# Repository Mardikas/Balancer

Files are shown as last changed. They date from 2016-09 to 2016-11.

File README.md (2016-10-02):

# Balancer
A (semi)self-driving (fully)self-balancing robot

Different PIDs:

	40;140;20 <--super stiff, but fails with strong tilts (overcompensates);
	40,90,80 <-- also quite stiff, does not overcompensate;

ToDo:

	*Try this PID library https://github.com/br3ttb/Arduino-PID-Library/blob/master/README.txt
	*Enable zeroing function for setpoint finding, so that when the machine stops for long enough, it will not start drifting in the other direction.
	*figure out a way (electronical preffered, mechanically different connections otherwise) to connect UNO and motor driver as a shield while still being able to use pin 2)
	EDIT: found a neat mechanical and aesthetical way to choose which pins to use
	*Gyro calibration offsets (MPU6050): acelX acelY acelZ giroX giroY giroZ -88	-290	2279	-599	39	15
	*Print out a good prototype chassis
	*Add encoder pin layout to PIN LAYOUT
	*Done:
		*Write a motor library (since default library doesn't work) //have implemented motor functions, but not in a separate library
		*Write simple code that keeps the robot upright //done more or less, perhaps needs even more fine tuning
		*Write simple code that enables for the robot to drive forward/backward, turn right and left //done, works semi-ok
		*Write a code for controlling the robot via bluetooth with Android //DONE!
	*Write a code for using encoders to keep speed/balance better; make balancing and driving code more ergonomical&better
	*Write code for mapping and then reproducing path
	*Write code for autonomous drive on a table withouth falling off nor bumping into obstacles
	*Write code for line following
	
	*Put a glass of water on robot and drive so

Done for now! Next step?

PIN LAYOUT:
	
	Gyro uses:
	
		*3.3V
		*GND
		*A4 (I2c) SDA
		*A5 (I2c) SCL
	
	Bluetooth uses:
	
		*3.3V
		*GND
		*D0(RX)
		*D1(TX)
	
	Motor shield uses:
	
		*D2 - Motor 1 direction input A
		*D4 - Motor 1 direction input B
		*D6 - Motor 1 enable input/fault output
		*D7 - Motor 2 direction input A
		*D8 - Motor 2 direction input B
		*D9 - Motor 1 speed input
		*D10 - Motor 2 speed input
		*D12 - Motor 2 enable input/fault output
		*A0 - Motor 1 current sense output - NOT USED
		*A1 Motor 2 current sense output - NOT USED
		*MUST share a common ground with Arduino
	
	Encoders use:
	
		*TBA!

Sources:
	High frequency PWM:
		http://forum.arduino.cc/index.php/topic,117425.0.html

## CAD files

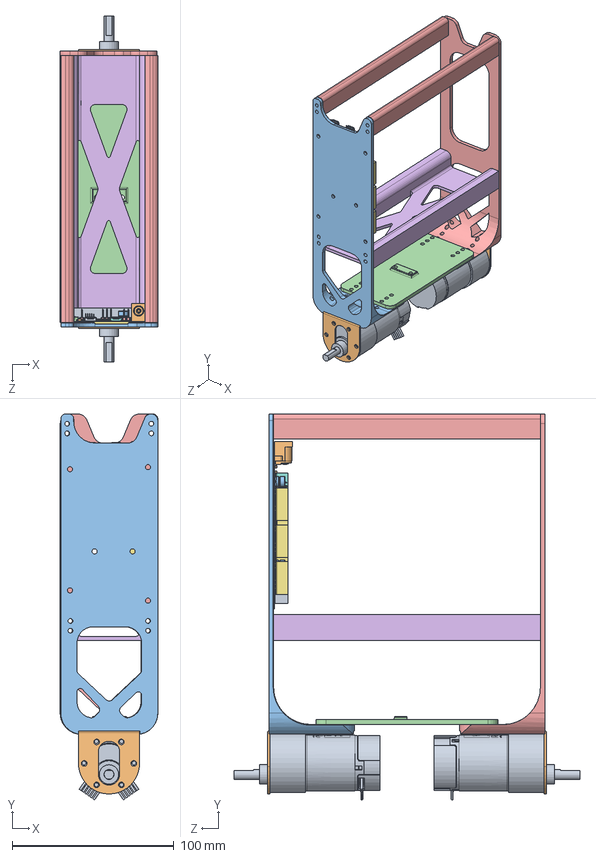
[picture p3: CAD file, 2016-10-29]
drawings/v2/Robot_assembly.SLDASM
60.4 x 238.7 x 213.7 mm
37d-gearmotor-19-30-encoder x 2
Pololu Stamped Aluminum L-Bracket Pair for 37D mm Metal Gearmotors x 2
Arduino_due_mount_wall
Horizontal_mount_battery_mount
Motor_controller_mount_wall_
horizontal_struct
PCB - Arduino
MicroUSB B - Hirose - ZX62D-B-5P8
MicroUSB AB - Hirose - ZX62D-AB-5P8
Power Jack - Kycon - KLDHCX-0202-A
LED - Kingbright - KPT-3216EC x 4
Microchip - Atmel - SAM3X8EAU
Berg Header - 2.54 x 2 x 8
Berg Header - 1.27 x 10
Berg Header Receptacle 2.54 x 8 - FCI - 66951-008LF x 5
Berg Header Receptacle 2.54 x 10 - FCI - 66951-010LF
Berg Header Receptacle 2.54 x 36 - FCI - 66953-018LF
Capacitor x 9
Capacitor - Nichicon - UUR1C101MCL1GS x 2
Switch - ESwitch - TLE3303
horizontal_struct_upper x 2

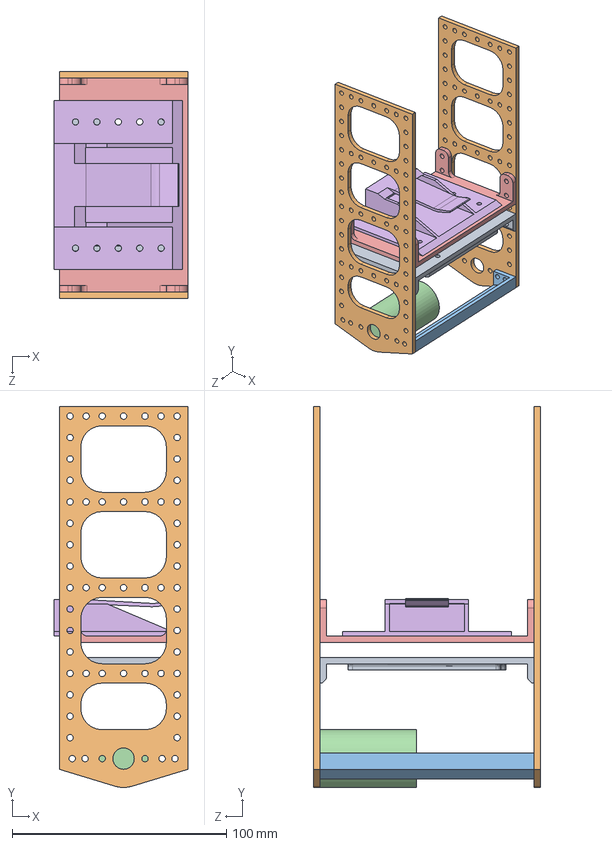
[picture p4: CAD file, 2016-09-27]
drawings/Solidworks/Assembly.SLDASM
62.5 x 178.0 x 106.0 mm
Arduino_mount_reviewed
vertical_panel x 2
struct_lower
motor
battery_mount_mount
battery_mount

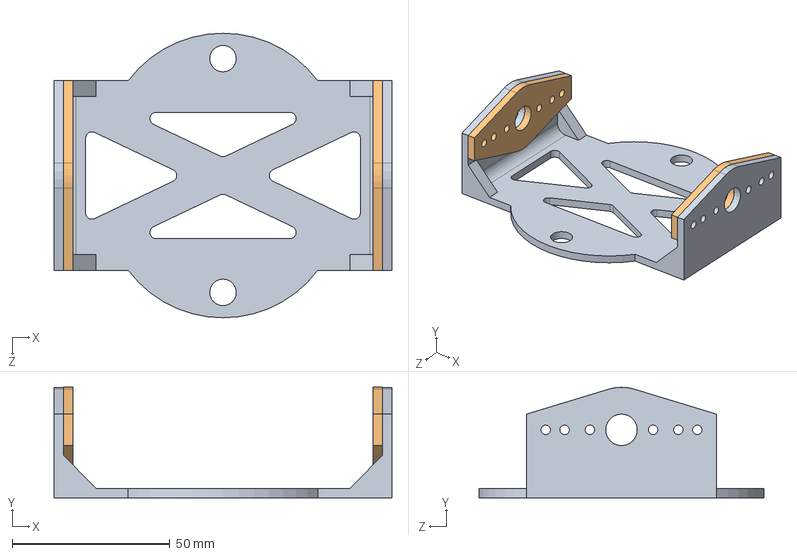
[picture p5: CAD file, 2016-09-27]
drawings/Solidworks/Assem1.SLDASM
107.0 x 35.0 x 90.1 mm
motor_floor
motor_mount x 2

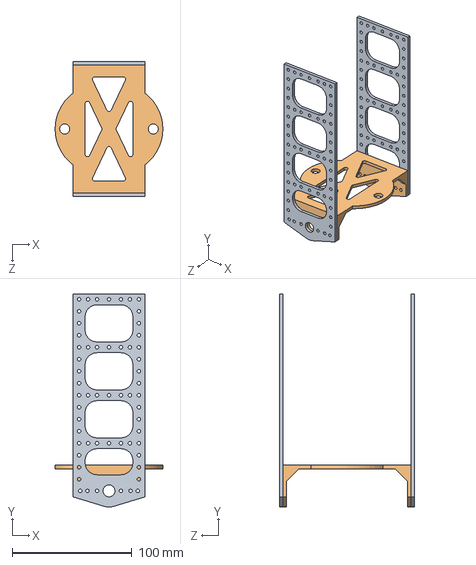
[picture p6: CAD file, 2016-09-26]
drawings/Solidworks/Robot_assembly.SLDASM
90.1 x 177.9 x 113.0 mm
vertical_panel x 2
motor_floor

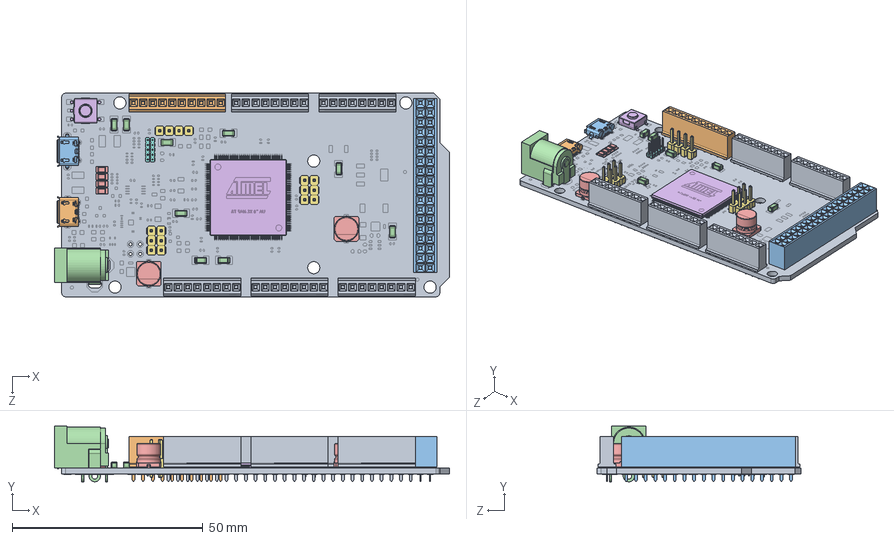
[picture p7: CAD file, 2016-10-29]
drawings/v2/Arduino Due/ARDUINO DUE.SLDASM
103.5 x 14.6 x 53.3 mm
PCB - Arduino
MicroUSB B - Hirose - ZX62D-B-5P8
MicroUSB AB - Hirose - ZX62D-AB-5P8
Power Jack - Kycon - KLDHCX-0202-A
LED - Kingbright - KPT-3216EC x 4
Microchip - Atmel - SAM3X8EAU
Berg Header - 2.54 x 2 x 8
Berg Header - 1.27 x 10
Berg Header Receptacle 2.54 x 8 - FCI - 66951-008LF x 5
Berg Header Receptacle 2.54 x 10 - FCI - 66951-010LF
Berg Header Receptacle 2.54 x 36 - FCI - 66953-018LF
Capacitor x 9
Capacitor - Nichicon - UUR1C101MCL1GS x 2
Switch - ESwitch - TLE3303

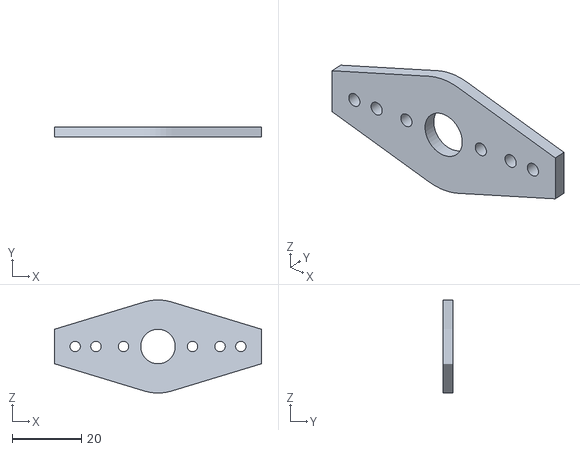
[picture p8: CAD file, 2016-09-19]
drawings/Printer/motor_mount.STL
60.0 x 3.00 x 27.0

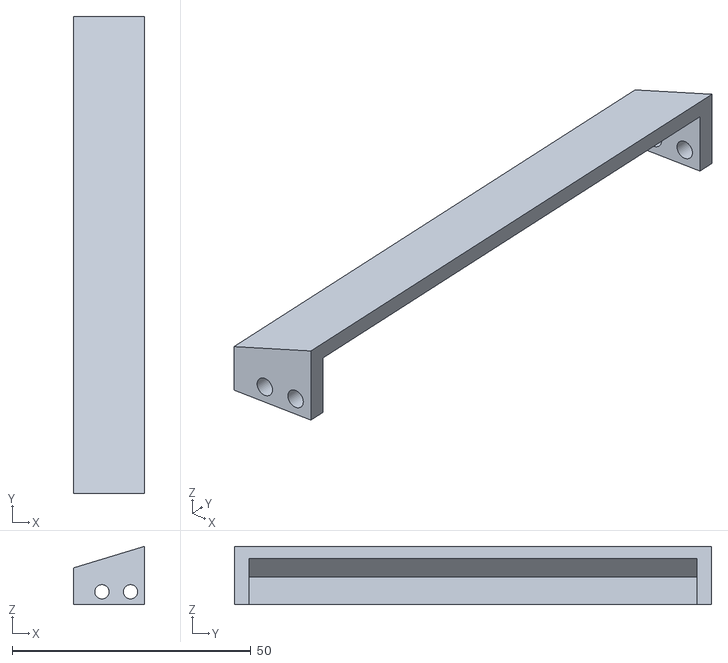
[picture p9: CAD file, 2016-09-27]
drawings/Printer/New_patch/struct_lower.STL
15.0 x 100.0 x 12.3

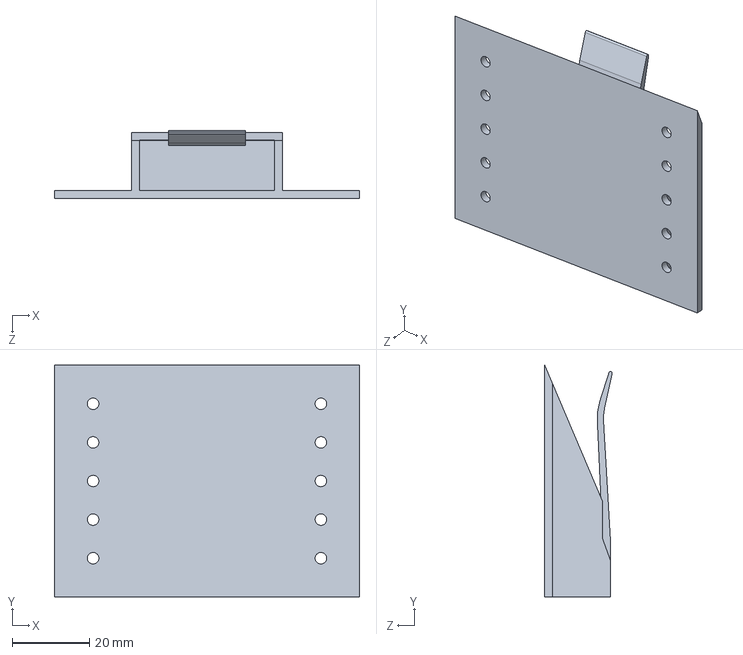
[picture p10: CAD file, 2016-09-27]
drawings/Solidworks/battery_mount.SLDPRT
79.0 x 60.0 x 17.5 mm

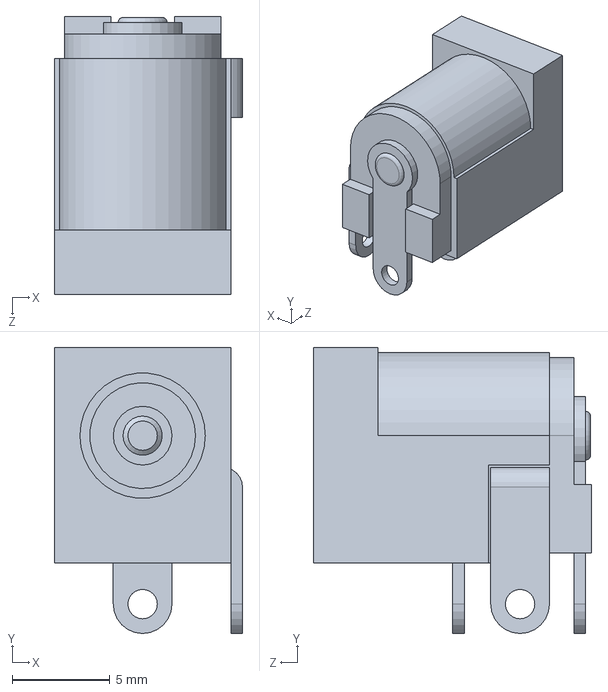
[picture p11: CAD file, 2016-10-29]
drawings/v2/Arduino Due/Power Jack - Kycon - KLDHCX-0202-A.SLDPRT
9.60 x 14.6 x 14.2 mm

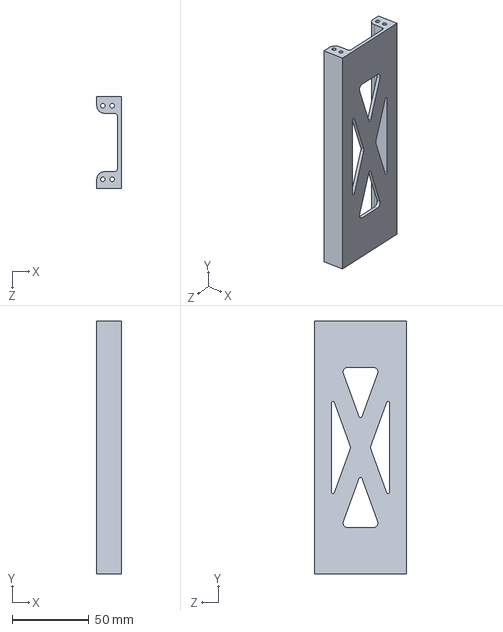
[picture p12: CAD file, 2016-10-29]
drawings/v2/horizontal_struct.SLDPRT
16.0 x 165.0 x 60.0 mm

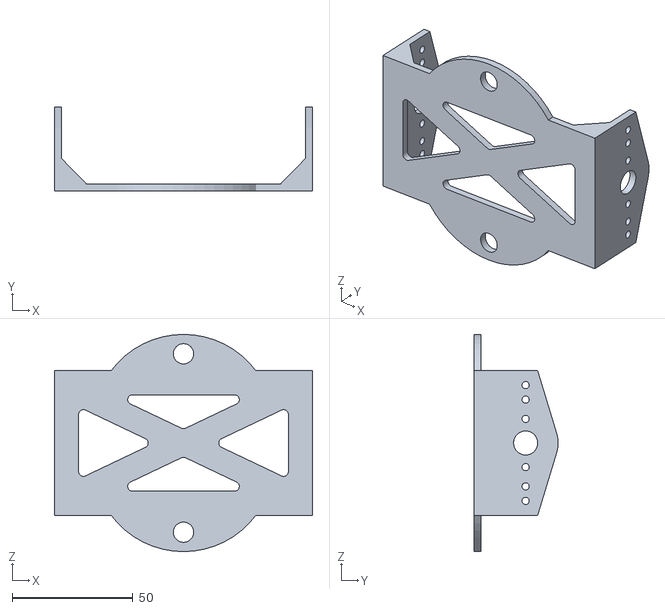
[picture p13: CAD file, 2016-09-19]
drawings/Printer/motor_floor.STL
107.0 x 35.0 x 90.1

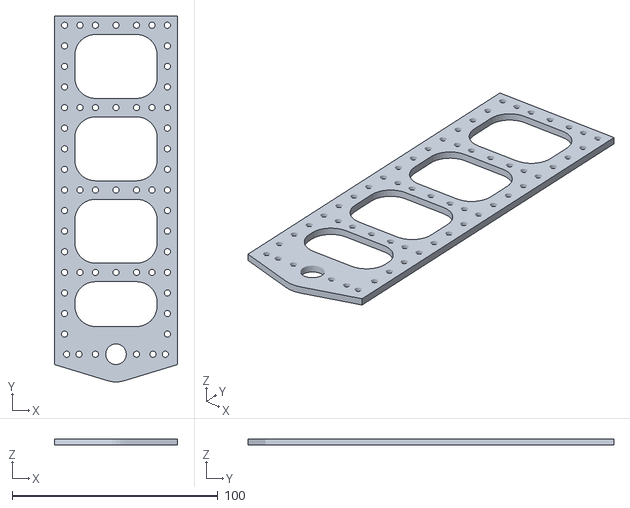
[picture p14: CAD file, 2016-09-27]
drawings/Printer/New_patch/vertical_panel.STL
60.0 x 178.0 x 3.00

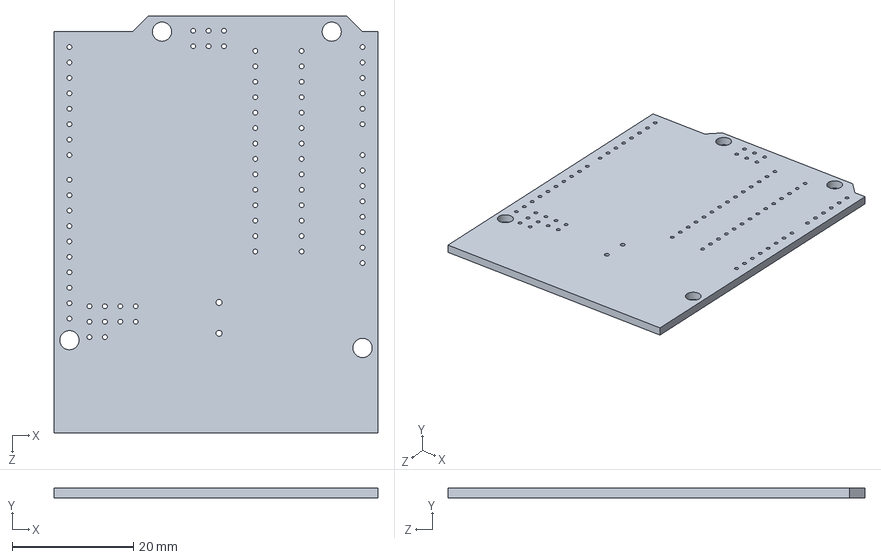
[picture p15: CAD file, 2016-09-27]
drawings/Solidworks/unoboard_blue.SLDPRT
53.3 x 1.65 x 68.6 mm

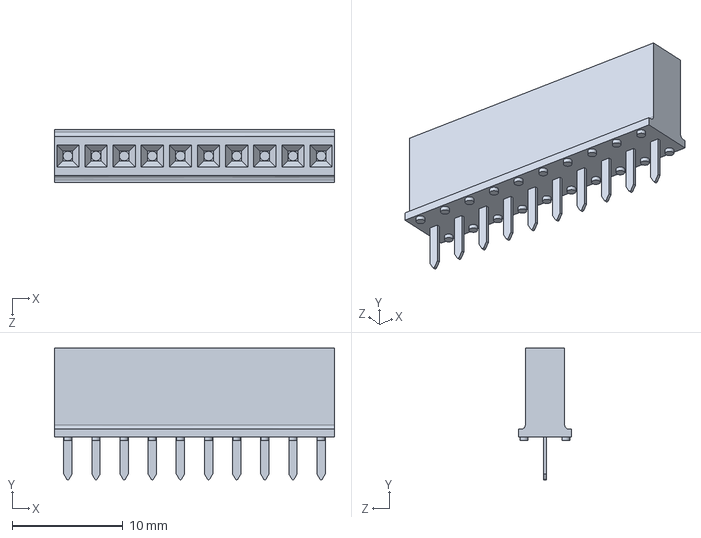
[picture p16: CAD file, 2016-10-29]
drawings/v2/Arduino Due/Berg Header Receptacle 2.54 x 10 - FCI - 66951-010LF.SLDPRT
25.3 x 11.9 x 4.78 mm

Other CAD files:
drawings/Printer/Arduino_MPU6050_Mount.STL
drawings/Printer/New_patch/battery_mount_mount.STL
drawings/Solidworks/Arduino_mount_reviewed.SLDPRT
drawings/v2/Arduino Due/Switch - ESwitch - TLE3303.SLDPRT
drawings/Printer/Motor_controller_mount.STL
drawings/Printer/New_patch/Arduino_mount_reviewed.STL
drawings/Printer/New_patch/battery_mount.STL
drawings/Solidworks/Arduino_MPU6050_Mount.SLDPRT
drawings/Solidworks/MPU6050_base.SLDPRT
drawings/Solidworks/Motor_controller_mount.SLDPRT
drawings/Solidworks/battery_mount_mount.SLDPRT
drawings/Solidworks/motor.SLDPRT
drawings/Solidworks/motor_floor.SLDPRT
drawings/Solidworks/motor_floor_rod_stabilizer.SLDPRT
drawings/Solidworks/motor_mount.SLDPRT
drawings/Solidworks/struct_lower.SLDPRT
drawings/Solidworks/vertical_panel.SLDPRT
drawings/v2/37d-gearmotor-19-30-encoder.SLDPRT
drawings/v2/37d-gearmotor-19-30-encoder.step
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

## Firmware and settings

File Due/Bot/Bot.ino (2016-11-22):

#include <PWM.h>
#include "DualVNH5019MotorShield.h"
DualVNH5019MotorShield md;
// EVERYTHING GYRO RELATED
#include "I2Cdev.h"
#include "MPU6050_6Axis_MotionApps20.h"
#if I2CDEV_IMPLEMENTATION == I2CDEV_ARDUINO_WIRE
  #include "Wire.h"
#endif

MPU6050 mpu;

#define INTERRUPT_PIN 24  // use pin 2 on Arduino Uno & most boards
bool dmpReady = false;  // set true if DMP init was successful
uint8_t mpuIntStatus;   // holds actual interrupt status byte from MPU
uint8_t devStatus;      // return status after each device operation (0 = success, !0 = error)
uint16_t packetSize;    // expected DMP packet size (default is 42 bytes)
uint16_t fifoCount;     // count of all bytes currently in FIFO
uint8_t fifoBuffer[64]; // FIFO storage buffer

Quaternion q;           // [w, x, y, z]         quaternion container
VectorInt16 aa;         // [x, y, z]            accel sensor measurements
VectorInt16 aaReal;     // [x, y, z]            gravity-free accel sensor measurements
VectorInt16 aaWorld;    // [x, y, z]            world-frame accel sensor measurements
VectorFloat gravity;    // [x, y, z]            gravity vector
float euler[3];         // [psi, theta, phi]    Euler angle container
float ypr[3];           // [yaw, pitch, roll]   yaw/pitch/roll container and gravity vector

volatile bool mpuInterrupt = false;     // indicates whether MPU interrupt pin has gone high
void dmpDataReady() {
    mpuInterrupt = true;
}

void gyro_init();
// END OF EVERYTHING GYRO RELATED

//////////////AVG ERROR CALCULATION STUFF////////////
#include "RunningAverage.h"
RunningAverage avg_error_array(200);
void calc_avg_error();
int avg_error;
/////////////////////////////////////////////////////
void calc_balance_PID();
void calc_setpoint_PID();
void receive_data();
void stopIfFault();
void receive_data();

char safety=0;

//Balancing PID related values
int error, P, D, last_P;
long I = 0;
int speed=0;
int I_gain_num = 3;
int I_gain_den = 1000;
int D_gain_num = 20;
int D_gain_den = 100;
int P_gain_num = 70;//numenator
int P_gain_den = 100;//denominator
int max_i = 200;
int target_speed=0;

//
//setpoint PID related values
int stp_error=0;
int last_stp_error=0;
long int stp_I=0;
int stp_P=0;
int stp_D=0;
int stp_P_gain=500;
int stp_I_gain=6600;
int stp_D_gain=150;

char buff[4];
float offset;
int turn;
int dir;
int turn_amount;
int direction_amount;
int remap_counter=0;
int remap_normalise_counter=0;
int remap_limit=10;
int setpoint_offset=0;
int motor_left=0;
int motor_right=0;

/////////////BEGINNING OF MOTOR STUFF/////////////
#include <Encoder.h>

Encoder motor_left_pos(38, 39);
Encoder motor_right_pos(40, 41);

int calc_motor_left_PWM();
int calc_motor_right_PWM();

int check_motor_safety();
//LEFT MOTOR STUFF
long motor_left_last_pos  = 0;
long motor_left_current_pos=0;
int motor_left_PWM=0;
int motor_left_current_speed=0;
int motor_left_target_speed=10;

int motor_left_speed_error=0;
int motor_left_P=0;
long motor_left_I=0;
int motor_left_D=0;
int motor_left_last_speed_error=0;

int motor_left_P_gain=10;
int motor_left_I_gain=1;
int motor_left_D_gain=10;

//RIGHT MOTOR STUFF
long motor_right_last_pos=0;
long motor_right_current_pos=0;
int motor_right_PWM=0;
int motor_right_current_speed=0;
int motor_right_target_speed=10;

int motor_right_speed_error=0;
int motor_right_P=0;
long motor_right_I=0;
int motor_right_D=0;
int motor_right_last_speed_error=0;

int motor_right_P_gain=10;
int motor_right_I_gain=1;
int motor_right_D_gain=10;

/////////////////END OF MOTOR STUFF//////////////

void printData();

// ================================================================
// ===                      INITIAL SETUP                       ===
// ================================================================

void setup() {
  
  gyro_init();
  md.init();
  
  P=I=D=error=last_P=0;
  dir=0;
  turn=0;
  turn_amount=100;
  direction_amount=5;
  target_speed=0;

  Serial1.begin(9600);
}



// ================================================================
// ===                    MAIN PROGRAM LOOP                     ===
// ================================================================

void loop() {
    receive_data();
    // if programming failed, don't try to do anything
    if (!dmpReady) return;

    // wait for MPU interrupt or extra packet(s) available
    while (!mpuInterrupt && fifoCount < packetSize) {
        // other program behavior stuff here
        // .
        // .
        // .
        // if you are really paranoid you can frequently test in between other
        // stuff to see if mpuInterrupt is true, and if so, "break;" from the
        // while() loop to immediately process the MPU data
        // .
        // .
        // .
        while((millis()%5)!=0);
       

        check_safety();
        if(safety!=0){
          md.setSpeeds(0,0);
        }
        //If robot is lying down, stop the motors

        //if it's not horisontal: DRIVE and BALANCE! :)
        else{
          calc_avg_error();
          calc_setpoint_PID();
          calc_balance_PID();
          //md.setSpeeds(motor_left_target_speed+turn+target_PWM, motor_right_target_speed-turn+target_PWM);
          md.setSpeeds(motor_left_PWM, motor_right_PWM);
        }
        printData();
    }

    // reset interrupt flag and get INT_STATUS byte
    mpuInterrupt = false;
    mpuIntStatus = mpu.getIntStatus();

    // get current FIFO count
    fifoCount = mpu.getFIFOCount();

    // check for overflow (this should never happen unless our code is too inefficient)
    if ((mpuIntStatus & 0x10) || fifoCount == 1024) {
        // reset so we can continue cleanly
        mpu.resetFIFO();
        Serial.println(F("FIFO overflow!"));

    // otherwise, check for DMP data ready interrupt (this should happen frequently)
    } else if (mpuIntStatus & 0x02) {
        // wait for correct available data length, should be a VERY short wait
        while (fifoCount < packetSize) fifoCount = mpu.getFIFOCount();

        // read a packet from FIFO
        mpu.getFIFOBytes(fifoBuffer, packetSize);
        
        // track FIFO count here in case there is > 1 packet available
        // (this lets us immediately read more without waiting for an interrupt)
        fifoCount -= packetSize;
            // display Euler angles in degrees
            mpu.dmpGetQuaternion(&q, fifoBuffer);
            mpu.dmpGetGravity(&gravity, &q);
            mpu.dmpGetYawPitchRoll(ypr, &q, &gravity);
        // blink LED to indicate activity
    }
}

void gyro_init(){
      // join I2C bus (I2Cdev library doesn't do this automatically)
    #if I2CDEV_IMPLEMENTATION == I2CDEV_ARDUINO_WIRE
        Wire.begin();
        Wire.setClock(400000); // 400kHz I2C clock. Comment this line if having compilation difficulties
    #elif I2CDEV_IMPLEMENTATION == I2CDEV_BUILTIN_FASTWIRE
        Fastwire::setup(400, true);
    #endif

    // initialize serial communication
    // (115200 chosen because it is required for Teapot Demo output, but it's
    // really up to you depending on your project)
    Serial.begin(115200);
    while (!Serial); // wait for Leonardo enumeration, others continue immediately

    // NOTE: 8MHz or slower host processors, like the Teensy @ 3.3v or Ardunio
    // Pro Mini running at 3.3v, cannot handle this baud rate reliably due to
    // the baud timing being too misaligned with processor ticks. You must use
    // 38400 or slower in these cases, or use some kind of external separate
    // crystal solution for the UART timer.

    // initialize device
    Serial.println(F("Initializing I2C devices..."));
    mpu.initialize();
    pinMode(INTERRUPT_PIN, INPUT);

    // verify connection
    Serial.println(F("Testing device connections..."));
    Serial.println(mpu.testConnection() ? F("MPU6050 connection successful") : F("MPU6050 connection failed"));

    // wait for ready

    // load and configure the DMP
    Serial.println(F("Initializing DMP..."));
    devStatus = mpu.dmpInitialize();

    // supply your own gyro offsets here, scaled for min sensitivity
    mpu.setXGyroOffset(-599);
    mpu.setYGyroOffset(39);
    mpu.setZGyroOffset(15);
    mpu.setZAccelOffset(2279);

    // make sure it worked (returns 0 if so)
    if (devStatus == 0) {
        // turn on the DMP, now that it's ready
        Serial.println(F("Enabling DMP..."));
        mpu.setDMPEnabled(true);

        // enable Arduino interrupt detection
        Serial.println(F("Enabling interrupt detection (Arduino external interrupt 0)..."));
        attachInterrupt(digitalPinToInterrupt(INTERRUPT_PIN), dmpDataReady, RISING);
        mpuIntStatus = mpu.getIntStatus();

        // set our DMP Ready flag so the main loop() function knows it's okay to use it
        Serial.println(F("DMP ready! Waiting for first interrupt..."));
        dmpReady = true;

        // get expected DMP packet size for later comparison
        packetSize = mpu.dmpGetFIFOPacketSize();
    } else {
        // ERROR!
        // 1 = initial memory load failed
        // 2 = DMP configuration updates failed
        // (if it's going to break, usually the code will be 1)
        Serial.print(F("DMP Initialization failed (code "));
        Serial.print(devStatus);
        Serial.println(F(")"));
    }
}


void calc_balance_PID(){
  
        //calc P
        P=(-ypr[2])*100+setpoint_offset;
        //P=P;
        /*if(ypr[2]<0){
          P=-P;
        }*/
        if(P>25){
          P=25;
        }
        else if(P<-25){
          P=-25;
        }
        //calc I
        I+=P;
        /*
        if(I>30000) I=300;
        else if(I<-300) I=-300;
        */


        //calc D
        D=P-last_P;

        //calc Total error
        error=(P*P_gain_num/P_gain_den) + (I*I_gain_num/I_gain_den) + (D*D_gain_num/D_gain_den);

        if(error>255){
          error=255;
        }
        else if(error<-255){
          error=-255;
        }
        //remember last error
        last_P=P;

        //assign total corrections to motors
        motor_right_target_speed=error;
        motor_left_target_speed=error;
        motor_right_PWM=calc_motor_right_PWM();
        motor_left_PWM=calc_motor_left_PWM();
}

void calc_setpoint_PID(){

      //stp_error=(error-target_PWM);
      stp_error=target_speed-((motor_right_current_speed+motor_left_current_speed)/2);
      stp_I+=stp_error;
      stp_D=stp_error-last_stp_error;
      setpoint_offset=stp_error/stp_P_gain+stp_I/stp_I_gain+stp_D/stp_D_gain;
      last_stp_error=stp_error;


}

void stopIfFault()
{
  if (md.getM1Fault())
  {
    Serial.println("M1 fault");
    while(1);
  }
  if (md.getM2Fault())
  {
    Serial.println("M2 fault");
    while(1);
  }
}

void receive_data(){

      if(Serial1.available()>2){
      buff[0]=Serial1.read();
      if(buff[0]=='d'){
        turn=Serial1.parseInt();
        turn=turn/2;
        dir=Serial1.parseInt();
        target_speed=map(dir, -512, 512, -150, 150);
      }
    else{
       
      if(buff[0]=='s'){
        buff[0]=Serial1.read();
          if(buff[0]=='p'){
            P_gain_num=Serial1.parseInt();
            Serial1.print("P_numerator set to ");
            Serial1.println(P_gain_num);
          }
          else if(buff[0]=='P'){
            P_gain_den=Serial1.parseInt();
            Serial1.print("P_denominator set to ");
            Serial1.println(P_gain_den);
          }
          else if(buff[0]=='D'){
            D_gain_den=Serial1.parseInt();
            Serial1.print("D_gain_denominator set to ");
            Serial1.println(D_gain_den);
          }
          else if(buff[0]=='I'){
            I_gain_den=Serial1.parseInt();
            Serial1.print("I_gain_denominator set to ");
            Serial1.println(I_gain_den);
          }
                    else if(buff[0]=='d'){
            D_gain_num=Serial1.parseInt();
            Serial1.print("D_gain_numenator set to ");
            Serial1.println(D_gain_num);
          }
          else if(buff[0]=='i'){
            I_gain_num=Serial1.parseInt();
            Serial1.print("I_gain_numenator set to ");
            Serial1.println(I_gain_num);
          }
          else if(buff[0]=='s'){
            buff[0]=Serial1.read();
            if(buff[0]=='p'){
              stp_P_gain=Serial1.parseInt();
              Serial1.print("stp_P_gain set to ");
              Serial1.println(stp_P_gain);
            }
            else if(buff[0]=='i'){
              stp_I_gain=Serial1.parseInt();
              Serial1.print("stp_I_gain set to ");
              Serial1.println(stp_I_gain);
            }
            else if(buff[0]=='d'){
              stp_D_gain=Serial1.parseInt();
              Serial1.print("stp_D_gain set to ");
              Serial1.println(stp_D_gain);
            }
          }
          
          
      }
    }     
  }
}

int calc_motor_right_PWM(){

  motor_right_current_pos = motor_right_pos.read();
  motor_right_current_speed=motor_right_current_pos-motor_right_last_pos;
  motor_right_last_pos=motor_right_current_pos;
  
  motor_right_speed_error=motor_right_target_speed-motor_right_current_speed;

  motor_right_P=motor_right_speed_error*motor_right_P_gain;
  motor_right_D=(motor_right_speed_error-motor_right_last_speed_error)*motor_right_D_gain;
  motor_right_I=motor_right_I+motor_right_speed_error;
  //motor_right_I=motor_right_I*motor_right_I_gain;

  //cap I
  
  if(motor_right_I>400){
    motor_right_I=400;
  }
  else if(motor_right_I<-400){
    motor_right_I=-400;
  }
  return (motor_right_P+(motor_right_I*motor_right_I_gain)+motor_right_D);
}

int calc_motor_left_PWM(){

  motor_left_current_pos = motor_left_pos.read();
  motor_left_current_speed=motor_left_current_pos-motor_left_last_pos;
  motor_left_last_pos=motor_left_current_pos;
  
  motor_left_speed_error=motor_left_target_speed-motor_left_current_speed;

  motor_left_P=motor_left_speed_error*motor_left_P_gain;
  motor_left_D=(motor_left_speed_error-motor_left_last_speed_error)*motor_left_D_gain;
  motor_left_I=motor_left_I+motor_left_speed_error;
  //motor_left_I=motor_left_I*motor_left_I_gain;

  //cap I
  
  if(motor_left_I>400){
    motor_left_I=400;
  }
  else if(motor_left_I<-400){
    motor_left_I=-400;
  }
  return (motor_left_P+(motor_left_I*motor_left_I_gain)+motor_left_D);
}

void check_safety(){
  int M1_current = md.getM1CurrentMilliamps();
  int M2_current = md.getM2CurrentMilliamps();
  safety=0;
  if(M2_current>1000&&M1_current<1000){
    safety=1;
  }
  else if(M1_current>1000&&M2_current<1000){
    safety=2;
  }
  else if(M1_current>1000&&M2_current>1000){
    safety=3;
  }
  if(ypr[2]>1||ypr[2]<(-1)){
    setpoint_offset=0;
    //md.setSpeeds(0,0);
    I=0;
    stp_I=0;
    safety=4;
  }
  /*
  if(safety>0&&safety<4){
    md.setSpeeds(0,0);
    delay(1000);
  }*/
}

void calc_avg_error(){
  avg_error_array.addValue(P);
  avg_error=avg_error_array.getAverage();
}

void printData(){

    Serial.print("avg error: ");
    Serial.println(avg_error);

}

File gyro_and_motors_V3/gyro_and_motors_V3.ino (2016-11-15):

//Somewhat ok PID settings: 130/10, 13/20, 90/10
//Even more stable:  135; 50; 16

//way better PID settings (IT ACTUALLY STAYS UPRIGHT): 100/10; 16/40; 55/10 


//Last PID: 140/10; 16/40; 120/10
#include <PWM.h>

#include "I2Cdev.h"

#include "MPU6050_6Axis_MotionApps20.h"

#include "DualVNH5019MotorShield.h"

// Arduino Wire library is required if I2Cdev I2CDEV_ARDUINO_WIRE implementation
// is used in I2Cdev.h

DualVNH5019MotorShield md;

#if I2CDEV_IMPLEMENTATION == I2CDEV_ARDUINO_WIRE
    #include "Wire.h"
#endif

#define MAX 255
#define ANGLE_MECHANICAL_CALIBRATION 0.1

MPU6050 mpu;

bool dmpReady = true;  // set true if DMP init was successful
uint8_t mpuIntStatus;   // holds actual interrupt status byte from MPU
uint8_t devStatus;      // return status after each device operation (0 = success, !0 = error)
uint16_t packetSize;    // expected DMP packet size (default is 42 bytes)
uint16_t fifoCount;     // count of all bytes currently in FIFO
uint8_t fifoBuffer[64]; // FIFO storage buffer

// orientation/motion vars
Quaternion q;           // [w, x, y, z]         quaternion container
VectorInt16 aa;         // [x, y, z]            accel sensor measurements
VectorInt16 aaReal;     // [x, y, z]            gravity-free accel sensor measurements
VectorInt16 aaWorld;    // [x, y, z]            world-frame accel sensor measurements
VectorFloat gravity;    // [x, y, z]            gravity vector
float ypr[3];           // [yaw, pitch, roll]   yaw/pitch/roll container and gravity vector


//ALL FUNCTIONS USED

void setM1Speed(int speed); // Set speed for M1.
void setM2Speed(int speed); // Set speed for M2.
void setSpeeds(int m1Speed, int m2Speed); // Set speed for both M1 and M2.
void setM1Brake(int brake); // Brake M1. 
void setM2Brake(int brake); // Brake M2.
void setBrakes(int m1Brake, int m2Brake);

void gyro_init();

void calc_balance_PID();
void calc_setpoint_PID();

void receive_data();

void stopIfFault();

//END OF FUNCTIONS

int avgPWM = 0;
int avgPWM_array[10];
int avgPWM_counter=0;



//Balancing PID related values
int error, P, D, last_P;
long I = 0;
int speed=0;
int I_gain_num = 33;
int I_gain_den = 40;
int D_gain_num = 550;
int D_gain_den = 10;
int P_gain_num= 209;//numenator
int P_gain_den=10;//denominator
int max_i=200;
int target_PWM=100;

//
//setpoint PID related values
int stp_error=0;
int last_stp_error=0;
long int stp_I=0;
int stp_P=0;
int stp_D=0;

/*
int stp_P_gain=500;
int stp_I_gain=750;
int stp_D_gain=200; good for just standing up
*/
int stp_P_gain=100;
int stp_I_gain=5050;
int stp_D_gain=150;
//

char buff[4];
float offset;
int turn;
int dir;
int turn_amount;
int direction_amount;
int remap_counter=0;
int remap_normalise_counter=0;
int remap_limit=10;
int setpoint_offset=0;
int motor_left=0;
int motor_right=0;

unsigned long controller_rst_timer;

void setup() {
  // put your setup code here, to run once:

   gyro_init();
   P=I=D=error=last_P=0;

dir=0;
turn=0;
turn_amount=100;
direction_amount=5;
target_PWM=0;
//zero avgPWM
for(avgPWM_counter=0;avgPWM_counter<9;avgPWM_counter++){
  avgPWM_array[avgPWM_counter]=0;
}
avgPWM_counter=0;
   Serial.begin(9600);
   md.init();
}


void loop() {
    //receive_data();
  // put your main code here, to run repeatedly:
      mpuIntStatus = mpu.getIntStatus();
    fifoCount = mpu.getFIFOCount();
    if ((mpuIntStatus & 0x10) || fifoCount == 1024) {
        mpu.resetFIFO();
    } else if (mpuIntStatus & 0x02) {
        while (fifoCount < packetSize) fifoCount = mpu.getFIFOCount();
        while((millis()%5)!=0);
        mpu.getFIFOBytes(fifoBuffer, packetSize);
        fifoCount -= packetSize;
            mpu.dmpGetQuaternion(&q, fifoBuffer);
            mpu.dmpGetGravity(&gravity, &q);
            mpu.dmpGetYawPitchRoll(ypr, &q, &gravity);


        //If robot is lying down, stop the motors
        if(ypr[2]>1||ypr[2]<(-1)){
          setpoint_offset=0;
          md.setSpeeds(0,0);
          I=0;
          stp_I=0;
        }
        //if it's not horisontal: DRIVE and BALANCE! :)
        else{
          calc_setpoint_PID();
          calc_balance_PID();
          
            md.setSpeeds(motor_left+turn+target_PWM, motor_right-turn+target_PWM);
        }
    }
}




//FUNCTIONS: 



/*void receive_data(){

      if(Serial.available()>2){
      buff[0]=Serial.read();
      if(buff[0]=='d'){
        turn=Serial.parseInt();
        turn=turn/2;
        dir=Serial.parseInt();
        target_PWM=map(dir, -512, 512, -150, 150);
      }
    else{
       
      if(buff[0]=='s'){
        buff[0]=Serial.read();
          if(buff[0]=='p'){
            P_gain_num=Serial.parseInt();
            Serial.print("P_numerator set to ");
            Serial.println(P_gain_num);
          }
          else if(buff[0]=='P'){
            P_gain_den=Serial.parseInt();
            Serial.print("P_denominator set to ");
            Serial.println(P_gain_den);
          }
          else if(buff[0]=='D'){
            D_gain_den=Serial.parseInt();
            Serial.print("D_gain_denominator set to ");
            Serial.println(D_gain_den);
          }
          else if(buff[0]=='I'){
            I_gain_den=Serial.parseInt();
            Serial.print("I_gain_denominator set to ");
            Serial.println(I_gain_den);
          }
                    else if(buff[0]=='d'){
            D_gain_num=Serial.parseInt();
            Serial.print("D_gain_numenator set to ");
            Serial.println(D_gain_num);
          }
          else if(buff[0]=='i'){
            I_gain_num=Serial.parseInt();
            Serial.print("I_gain_numenator set to ");
            Serial.println(I_gain_num);
          }
          else if(buff[0]=='s'){
            buff[0]=Serial.read();
            if(buff[0]=='p'){
              stp_P_gain=Serial.parseInt();
              Serial.print("stp_P_gain set to ");
              Serial.println(stp_P_gain);
            }
            else if(buff[0]=='i'){
              stp_I_gain=Serial.parseInt();
              Serial.print("stp_I_gain set to ");
              Serial.println(stp_I_gain);
            }
            else if(buff[0]=='d'){
              stp_D_gain=Serial.parseInt();
              Serial.print("stp_D_gain set to ");
              Serial.println(stp_D_gain);
            }
          }
          
          
      }
    }     
  }
}
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

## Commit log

2016-09-13 Add files via upload
    This code initializes a gyro and outputs it's values.
    Uses MPU6050_6Axis_MotionApps20.h library that can be found here: https://github.com/jrowberg/i2cdevlib/tree/master/Arduino/MPU6050
    Uses I2Cdev.h; Wire.h
2016-09-16 Create bluetooth_copy.ino
    This code reads a message from bluetooth and outputs it to arduino serial
2016-09-22 Update and rename motor_control_v2.ino to motor_control_almost_library.ino
    Good, self-written library - BUT NOT YET IMPLEMENTED AS LIBRARY
    This code sets both motors driving at full speed
    has useful commands (setspeeds(), brake(), etc)
2016-09-24 Update gyro_and_motors.ino
    Added bluetooth PID setting. Robot now somewhat kinda stays upright
2016-09-24 Update gyro_and_motors.ino
    Put the whole motor steering into gyro function so that PID would actually work
2016-09-25 Update gyro_and_motors.ino
    added rudimentary turning and forward/backward drive. Driving forward/backward doesn't currently work, because robot tries to maintain a slight tilt, which leads to perpetum acceleration, and at one point, motors are going so fast that they are capped at one end.
    Gonna try a fix, where robot tries to instead get the motor's speed up to a certain point, but when that point is reached, the robot will try to balance itself on the standing still point, instead of that tilt point.
    [gyro_and_motors.ino]
2016-09-25 Update gyro_and_motors.ino
    Now uses a joystick drive with an android app. Todo: Make it more stable and add a method to recognize when it is going too fast to keep up and take measures to prevent it (either by tuning pid or by detecting motors speed and setting a new zero reference point whenever motors are going too fast)
    TL;DR: tune the settings so that the robot will never topple over in normal settings or with slight nudging.
    [gyro_and_motors.ino]
2016-09-26 Since carbon rods are too short AND unstable, I made a vertical panel instead. This gives the robot more stability.
    [vertical_panel.SLDPRT]
2016-09-30 Update gyro_and_motors.ino
    Added automatic setpoint finding
2016-10-14 Update gyro_and_motors_V2.ino
    PID is now a useful one
